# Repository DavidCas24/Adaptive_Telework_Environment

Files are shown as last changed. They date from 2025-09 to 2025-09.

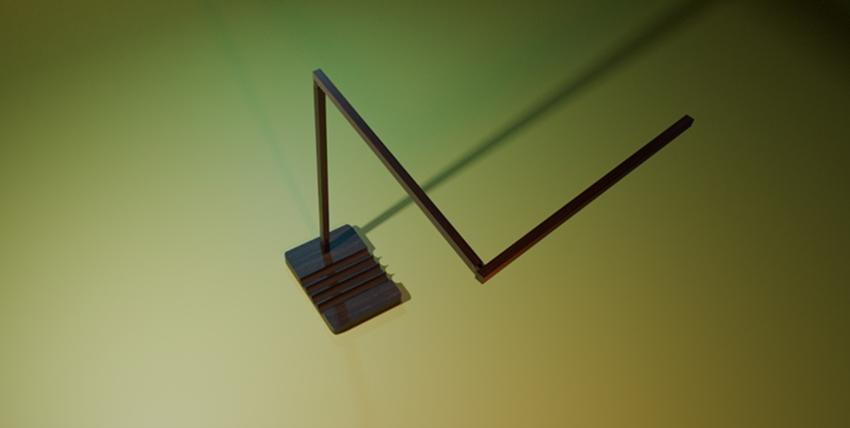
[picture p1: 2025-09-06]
HARDWARE/Render_lamp.png

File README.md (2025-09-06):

# Adaptive Telework Environment with AI-based Smart Lighting

## Overview

This project—developed as part of the IoT Master's Thesis at UNIR—focuses on designing and implementing a cyber-physical smart lamp. It integrates environmental sensors, edge-level AI, IoT connectivity, and dynamic lighting to monitor and classify workspace conditions, ultimately enhancing comfort, productivity, and well-being for remote and hybrid workers.

Render_lamp

## Key Features

- Custom PCB integrating sensors: temperature, humidity, light spectrum, noise, CO₂, VOCs.
- Dynamic lighting control based on open-source WLED.
- TinyML (with Edge Impulse) model on the edge to classify environments as *good, moderate,* or *bad*.
- Real-time visualization via Datacake.
- Interactive online 3D model accessible at: https://lurmis.vercel.app/en

## Repository Structure

Here’s the layout of the project and what each part contains:

```text
HARDWARE/                  → PCB designs, schematics, Gerber files used for fabrication
PCB/                       → Specific PCB layout files (KiCad, Gerber)
Tiny Firmware/             → Minimal firmware examples or template for microcontroller
README.md                  → This documentation file
```
---

##  3D Model

Explore the interactive 3D model of the smart lamp here:
https://lurmis.vercel.app/en

##  Getting Started

1. Clone this repository.
2. Inspect the HARDWARE/ and PCB/ folders for PCB design sources.
3. Use the Tiny Firmware/ folder to explore or flash firmware.
4. Follow the README instructions in each folder to assemble, program, and visualize your setup.

---

##  Dashboard Example / Ejemplo de Dashboard

[Public Datacake Dashboard Example](https://app.datacake.de/dashboard/d/b61564c8-49cd-4808-8c22-bb57cf323bb0)

---

##  System Architecture



---

##  Acknowledgments

SEEEDSTUDIO Fusion PCB Service for sponsoring the manufacturing and assembly of our PCBs and UNIR – Universidad Internacional de La Rioja for the academic guidance.

---

##  License

This project is released under the [MIT License].

---

✍️ Developed by
**David Felipe Castiblanco Cantor** & **Óscar Martínez Cueto**  
Master in IoT – UNIR, 2025

------------------------------------------------------------------------

# Entorno de teletrabajo adaptativo con iluminación inteligente basada en IA

## Resumen

Este proyecto, desarrollado como parte del Trabajo Fin de Máster en IoT en la UNIR, se centra en el diseño e implementación de una lámpara inteligente ciberfísica. Integra sensores ambientales, IA de vanguardia, conectividad IoT e iluminación dinámica para monitorizar y clasificar las condiciones del espacio de trabajo, mejorando así la comodidad, la productividad y el bienestar de los trabajadores remotos e híbridos.

Render_lamp

## Características principales

- PCB personalizada que integra sensores: temperatura, humedad, espectro luminoso, ruido, CO₂, COV.
- Control dinámico de la iluminación basado en WLED de código abierto. - Modelo TinyML (con Edge Impulse) en el borde para clasificar entornos como *buenos, moderados* o *malos*.
- Visualización en tiempo real mediante Datacake.
- Modelo 3D interactivo en línea disponible en: https://lurmis.vercel.app/en

## Estructura del repositorio

A continuación, se muestra el diseño del proyecto y el contenido de cada parte:

```texto
HARDWARE/ → Diseños de PCB, esquemas y archivos Gerber utilizados para la fabricación
PCB/ → Archivos específicos de diseño de PCB (KiCad, Gerber)
Tiny Firmware/ → Ejemplos mínimos de firmware o plantilla para microcontrolador
README.md → Este archivo de documentación
```
---

## Modelo 3D

Explora el modelo 3D interactivo de la lámpara inteligente aquí:
https://lurmis.vercel.app/en

## Primeros pasos

1. Clona este repositorio.
2. Revise las carpetas HARDWARE/ y PCB/ para encontrar las fuentes de diseño de PCB.

3. Use la carpeta Tiny Firmware/ para explorar o actualizar el firmware.

4. Siga las instrucciones del archivo README en cada carpeta para ensamblar, programar y visualizar su configuración.

---

## Ejemplo de Dashboard / Ejemplo de Dashboard

[Ejemplo de Dashboard Público de Datacake](https://app.datacake.de/dashboard/d/b61564c8-49cd-4808-8c22-bb57cf323bb0)

---

## Arquitectura del Sistema



---

## Agradecimientos

A SEEEDSTUDIO Fusion PCB Service por el patrocinio de la fabricación y el ensamblaje de nuestras PCB y a UNIR – Universidad Internacional de La Rioja por la orientación académica.

---

## Licencia

Este proyecto se publica bajo la [Licencia MIT].

---

✍️ Desarrollado por:  
**David Felipe Castiblanco Cantor** & **Óscar Martínez Cueto**  
Master in IoT – UNIR, 2025

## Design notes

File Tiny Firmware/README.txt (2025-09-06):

Run Particle library

The Particle Library deployment option packages all your signal processing blocks, configuration and learning blocks up into a single library (.zip file). You can include this library in your own application to run the impulse locally.

Particle Libraries

To run your Impulse on your Particle board follow these steps:

1. Open a new VS Code window, ensure that Particle Workbench has been installed.
2. Use VS Code Command Palette and type in Particle: Import Project
	a. Select the project.properties file in the directory that you just downloaded and extracted from the section above.
3. Use VS Code Command Palette and type in Particle: Configure Project for Device
	a. Select deviceOS@5.3.2 (or a later version)
	b. Choose a target. (e.g. P2 , this option is also used for the Photon 2).
4. It is sometimes needed to manually put your Device into DFU Mode. You may proceed to the next step, but if you get an error indicating that “No DFU capable USB device available” then please follow these step.
	a. Hold down both the RESET and MODE buttons.
	b. Release only the RESET button, while holding the MODE button.
	c. Wait for the LED to start flashing yellow.
	b. Release the MODE button.
5. Compile and Flash in one command with: Particle: Flash application & DeviceOS (local).

More information: https://docs.edgeimpulse.com/tutorials/topics/inference/run-particle

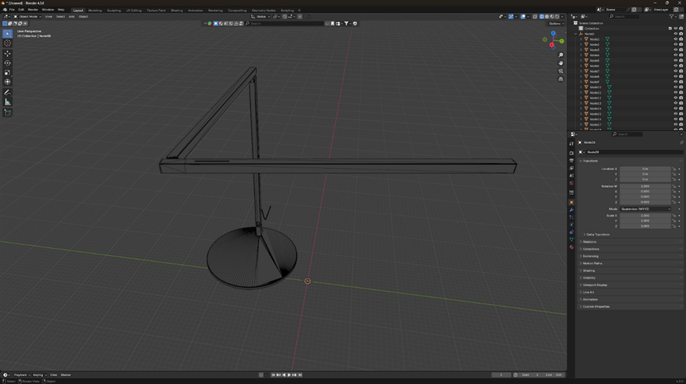
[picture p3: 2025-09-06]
HARDWARE/Blender_desing_lamp.png

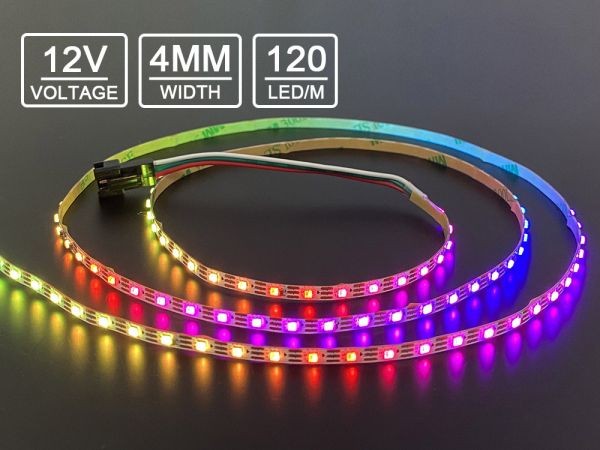
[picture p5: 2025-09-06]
HARDWARE/WS2812B_12V_RBG.jpg

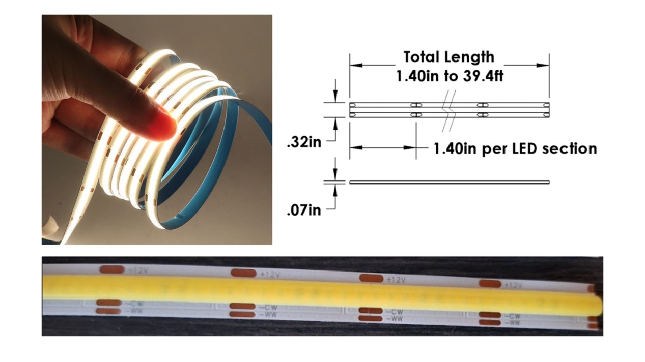
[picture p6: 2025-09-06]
HARDWARE/12V_COB_LED.jpg

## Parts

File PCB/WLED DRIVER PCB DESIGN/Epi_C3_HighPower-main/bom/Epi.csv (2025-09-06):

null | Sourced | Placed | References | Value | Footprint | Quantity
1 |  |  | C1, C8, C11, C13 | 1µF | C_0402_1005Metric | 4
2 |  |  | C16, C17 | 22µF | C_0805_2012Metric | 2
3 |  |  | C10 | 10µF | C_0805_2012Metric | 1
4 |  |  | C15 | 100nF | C_0402_1005Metric | 1
5 |  |  | R6, R7, R9, R10, R11, R12, R13, R14 | 10K | R_0402_1005Metric | 8
6 |  |  | R3, R8, R15 | 1K | R_0402_1005Metric | 3
7 |  |  | R1 | TBD | R_0402_1005Metric | 1
8 |  |  | L2 | TBD | L_Abracon_ASPI-0425 | 1
9 |  |  | D1 | D_Small | D_SOD-128 | 1
10 |  |  | U1 | ESP32-C3-MINI-1 | ESP32-C3-MINI-1 | 1
11 |  |  | U2 | MIC5219-3.3YM5 | SOT-23-5 | 1
12 |  |  | U3 | ~ | SOIC-10_3.9x4.9mm_P1mm | 1
13 |  |  | U5 | AP63205WU | TSOT-23-6 | 1
14 |  |  | SW2 | SW_MEC_5G | R-668048 | 1
15 |  |  | JP1, JP2, JP3, JP4 | Jumper | SolderJumper-2_P1.3mm_Open_RoundedPad1.0x1.5mm | 4
16 |  |  | Q1, Q2, Q3, Q4 | Q_NMOS_GSD | SOT-23 | 4
17 |  |  | RV3 | Varistor | R_0402_1005Metric | 1
18 |  |  | J1 | Conn_01x08 | PinHeader_1x08_P2.54mm_Vertical | 1
19 |  |  | J2 | USB_C_Receptacle_USB2.0 | USB_C_Receptacle_G-Switch_GT-USB-7010ASV | 1
20 |  |  | J4 | Conn_01x01 | TestPoint_Pad_3.0x3.0mm | 1
21 |  |  | J5 | Conn_01x09 | PinHeader_1x09_P2.54mm_Vertical | 1
22 |  |  | J7 | Conn_02x03 | PinHeader_2x03_P2.54mm_Horizontal | 1
23 |  |  | J8 | Conn_01x03 | PinHeader_1x03_P2.54mm_Vertical | 1

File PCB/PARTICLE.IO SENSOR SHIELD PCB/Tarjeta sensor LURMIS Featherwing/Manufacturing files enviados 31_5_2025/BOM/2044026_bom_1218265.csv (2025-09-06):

Designator | Manufacturer Part Number or Seeed SKU | Quantity | Link
U2 | AB1805-T3 | 1 | https://item.hqchip.com/1102748861.html
R1 | RC0603JR-071K5L | 1
R2,R3 | RMCF0603JT10K0 | 2 | https://item.hqchip.com/1101293532.html
Q1 | ABS07-120-32.768KHZ-T | 1
C3 | EMCP500G470M1GV001T | 1 | https://item.hqchip.com/1100650671.html
R4,R5 | RG1608P-104-B-T5 | 2 | https://item.hqchip.com/1101325767.html
Q2 | 2N7002L | 1 | https://item.hqchip.com/1103150596.html
U1 | AS7341-DLGT | 1 | https://item.hqchip.com/1105780271.html
R6,R7,R8 | CRGCQ0603J2K2 | 3 | https://item.hqchip.com/1105771346.html
C5 | CC0603KRX7R7BB104 | 1
U3 | AP2127K-1.8TRG1 | 1 | https://item.hqchip.com/1103060261.html
C2,C4 | CL10B105KP8NNNC | 2
R9,R10,R11 | CR0603-JW-102ELF | 3 | https://item.hqchip.com/1101334259.html
D1 | LTST-C190KRKT | 1 | https://item.hqchip.com/1100067616.html
D2 | MP-3014-1100-50-70 | 1 | https://item.hqchip.com/1106299875.html
D3 | APT1608SF4C-PRV | 1 | https://item.hqchip.com/1103075460.html
J1 | SM04B-SRSS-TB(LF)(SN) | 1
D4,D5 | LTST-C190GKT | 2 | https://item.hqchip.com/1100067619.html
JP1 | TSM-102-01-L-SV | 1 | https://item.hqchip.com/1102248009.html
JP3 | TSM-105-01-L-SV | 1 | https://item.hqchip.com/1036858135.html

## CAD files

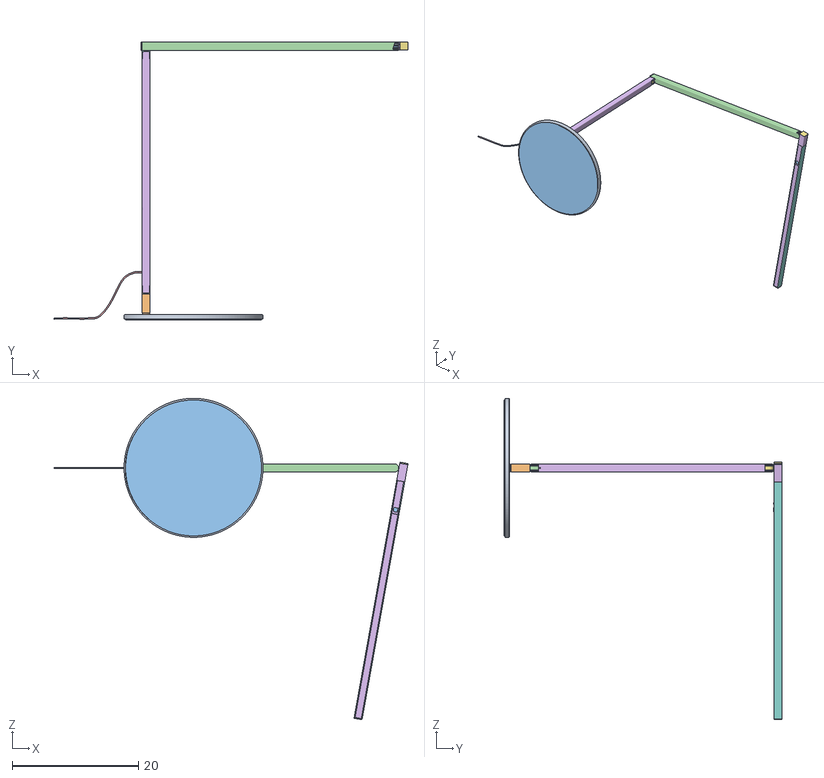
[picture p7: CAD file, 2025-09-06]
HARDWARE/DISEÑO_LAMPARA_3D/Z-Bar Gen 4.obj
56.0 x 44.0 x 50.8

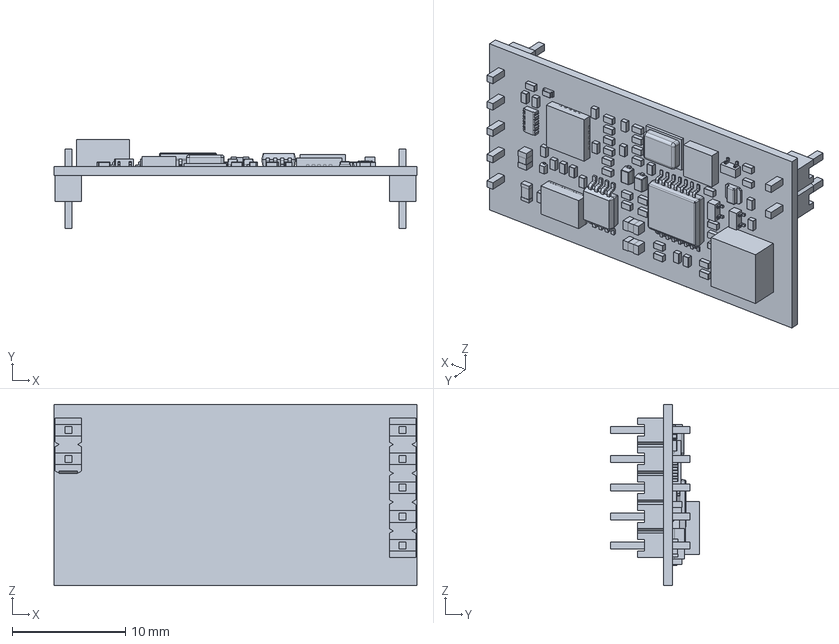
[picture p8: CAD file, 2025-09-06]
PCB/3D/Ambimate.stp
32.0 x 7.84 x 16.0 mm

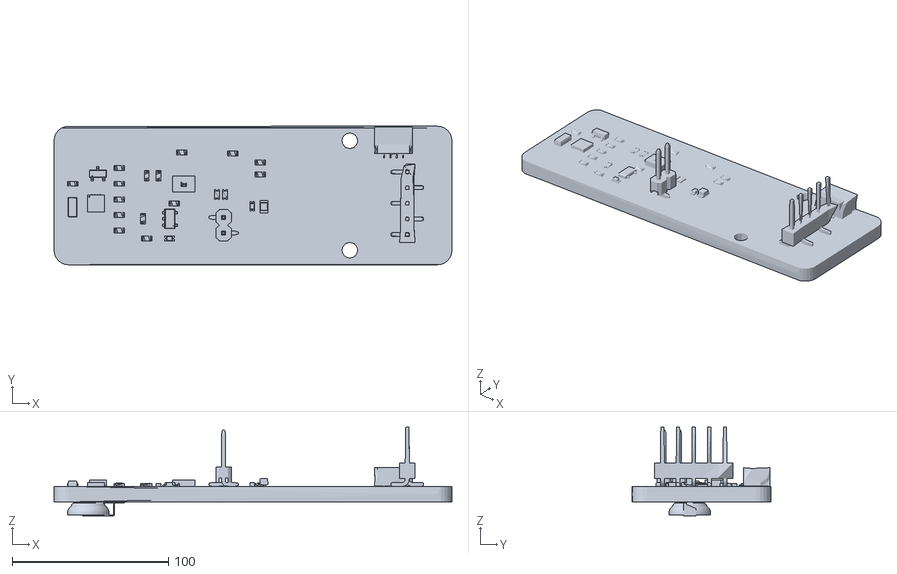
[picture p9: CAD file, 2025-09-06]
PCB/PARTICLE.IO SENSOR SHIELD PCB/MECHANICAL Modelo 3D/OBJ_FeatherAB1805-SC_FINAL_2.obj
254.8 x 88.8 x 56.8

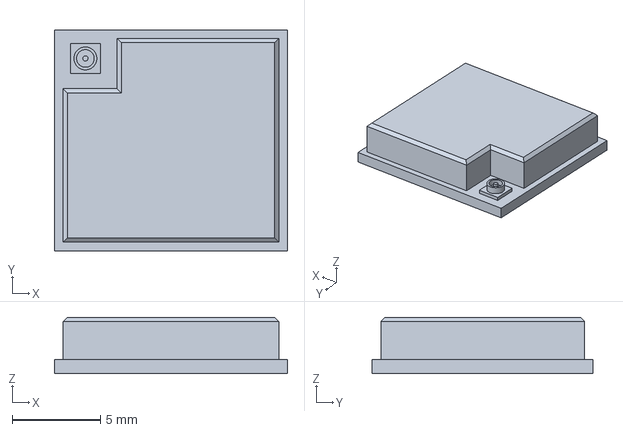
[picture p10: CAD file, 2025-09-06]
PCB/WLED DRIVER PCB DESIGN/Epi_C3_HighPower-main/ESP32-C3-MINI-1U.FCStd
13.2 x 12.5 x 3.20 mm

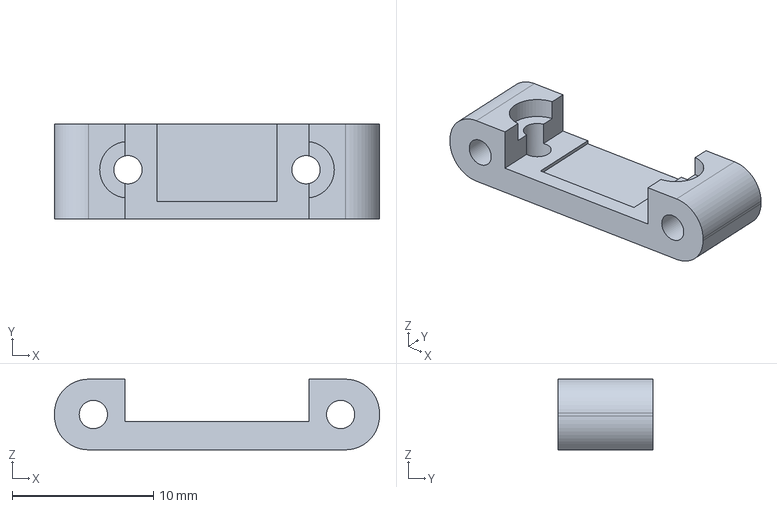
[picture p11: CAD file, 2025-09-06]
PCB/WLED DRIVER PCB DESIGN/Epi_C3_HighPower-main/extra/panelmount.FCStd
23.0 x 6.75 x 5.00 mm

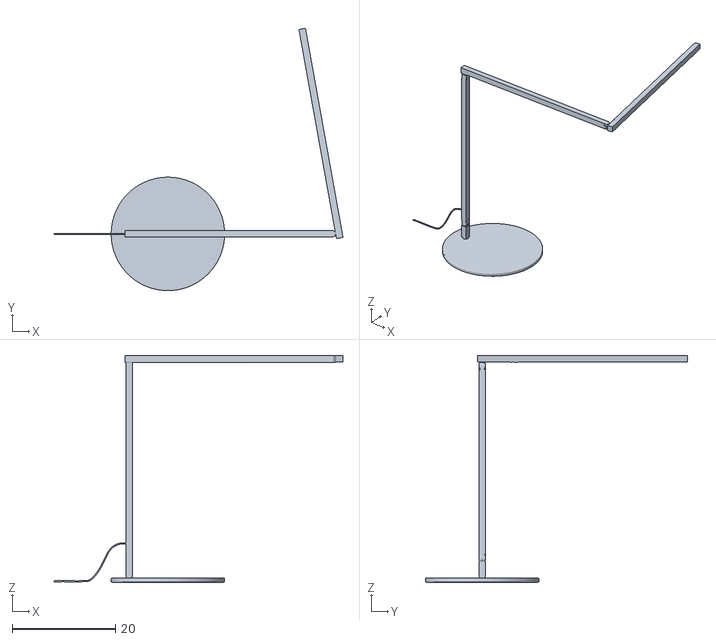
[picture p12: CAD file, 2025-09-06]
HARDWARE/DISEÑO_LAMPARA_3D/lampara.stl
56.0 x 50.8 x 44.0

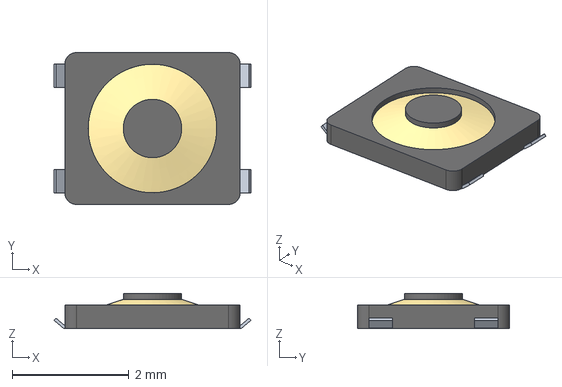
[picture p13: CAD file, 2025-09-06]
PCB/WLED DRIVER PCB DESIGN/Epi_C3_HighPower-main/extra/knapp (2023_01_16 13_30_41 UTC).stp
3.37 x 2.60 x 0.6 mm

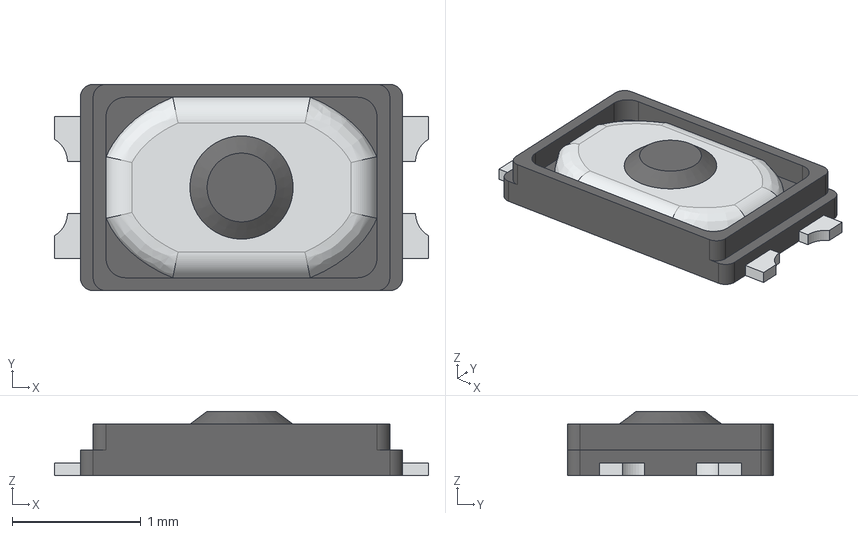
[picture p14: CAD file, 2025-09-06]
PCB/WLED DRIVER PCB DESIGN/Epi_C3_HighPower-main/extra/R-668048_sw.stp
2.90 x 1.60 x 0.5 mm

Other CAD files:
PCB/PARTICLE.IO SENSOR SHIELD PCB/MECHANICAL Modelo 3D/argon-v1.f3d
PCB/WLED DRIVER PCB DESIGN/Epi_C3_HighPower-main/extra/panelmount.obj

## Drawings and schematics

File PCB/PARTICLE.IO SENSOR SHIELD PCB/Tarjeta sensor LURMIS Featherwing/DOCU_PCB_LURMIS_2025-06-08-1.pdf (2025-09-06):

A | A

1

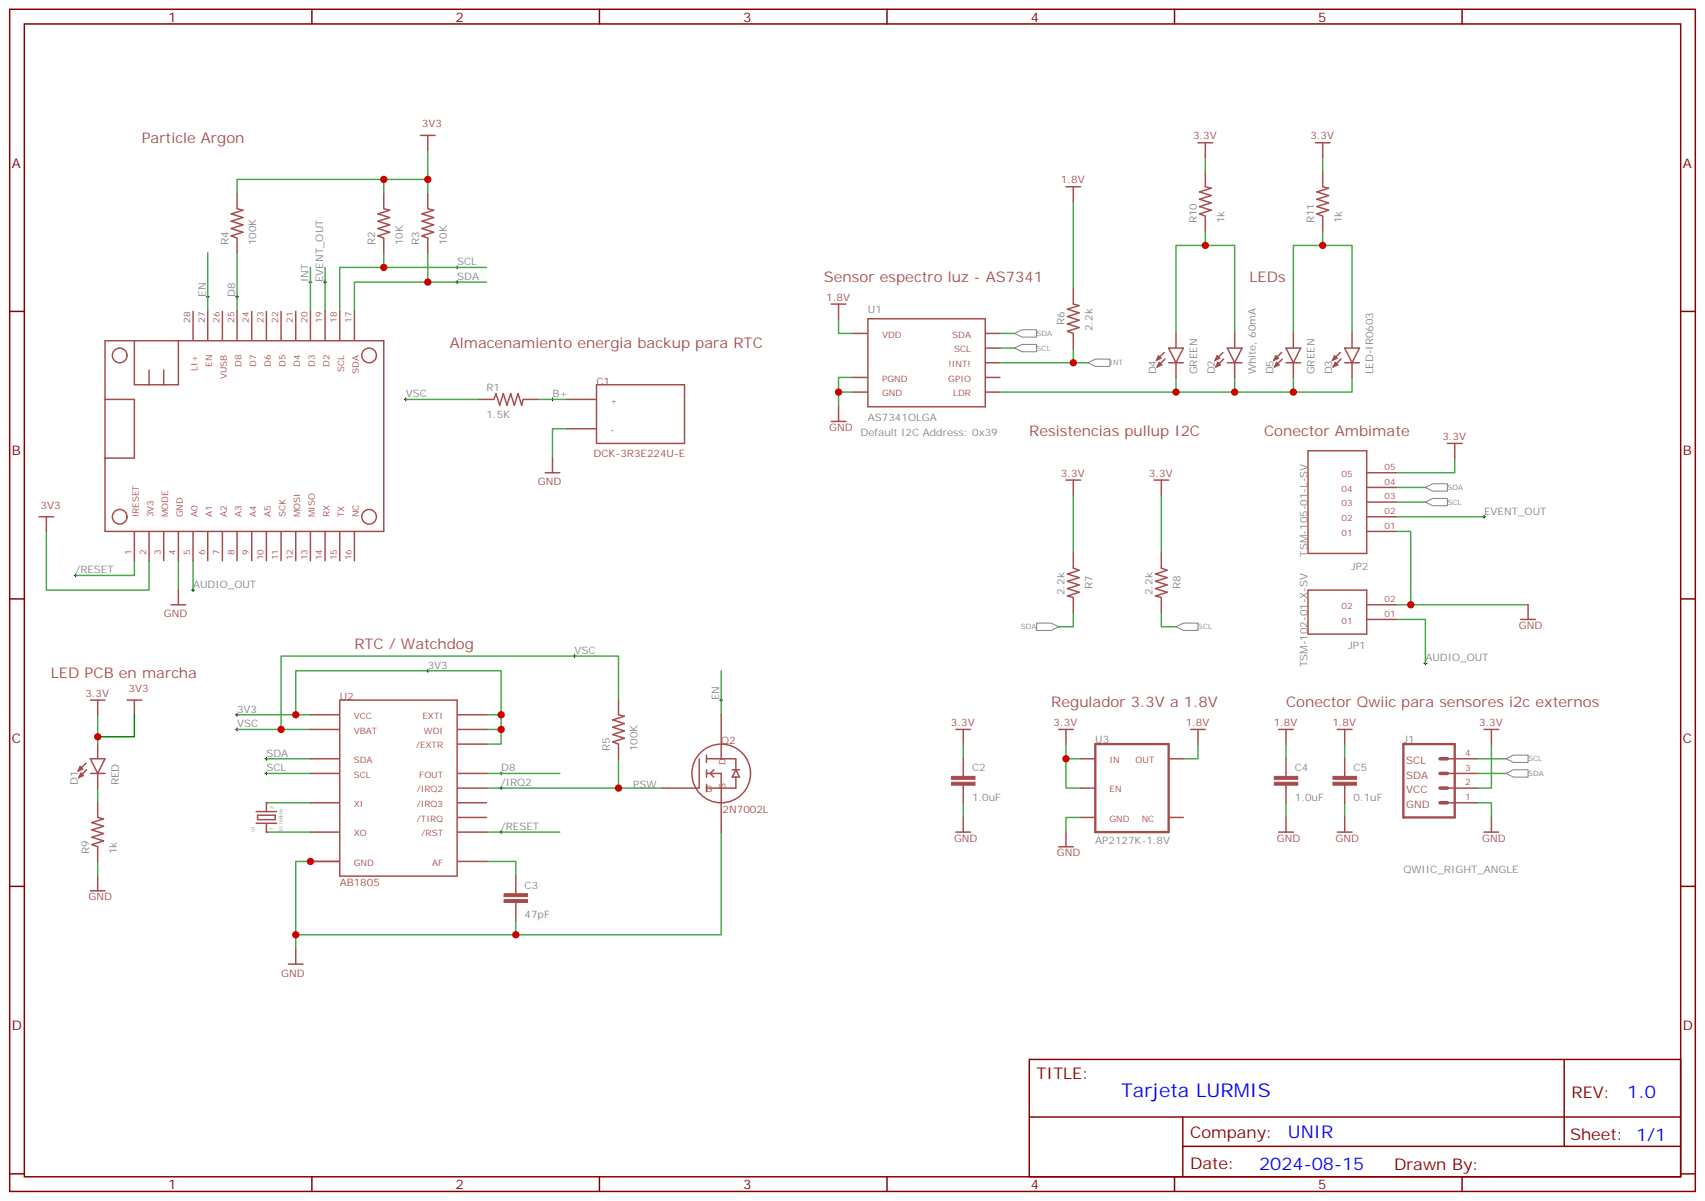
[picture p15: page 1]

Almacenamiento energia backup para RTC

LED PCB en marcha

Conector Qwiic para sensores i2c externos

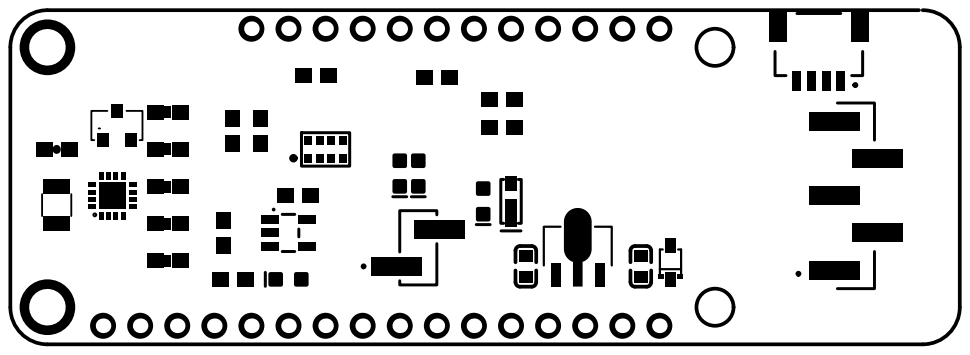
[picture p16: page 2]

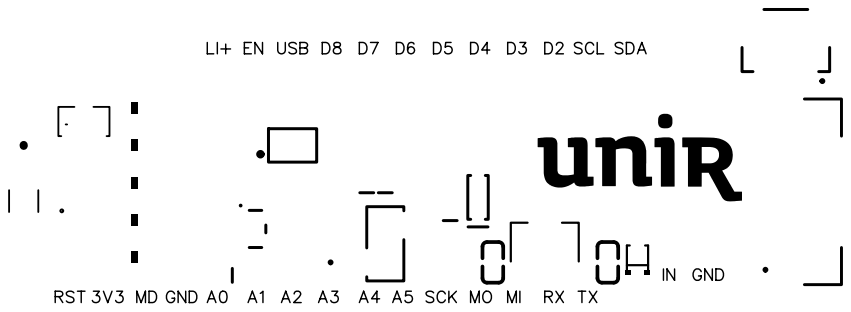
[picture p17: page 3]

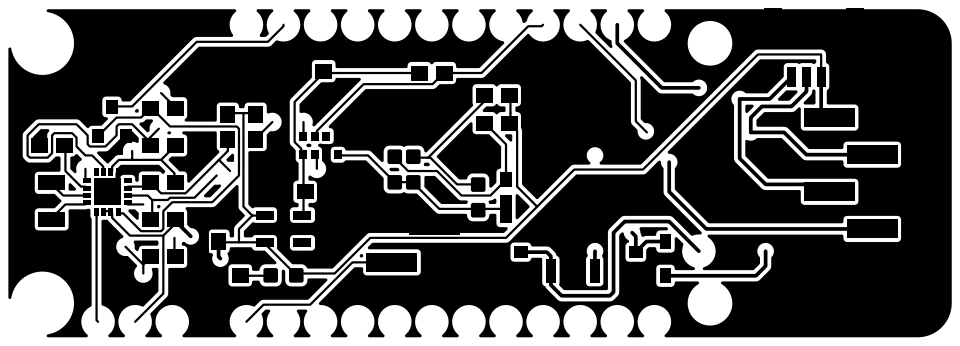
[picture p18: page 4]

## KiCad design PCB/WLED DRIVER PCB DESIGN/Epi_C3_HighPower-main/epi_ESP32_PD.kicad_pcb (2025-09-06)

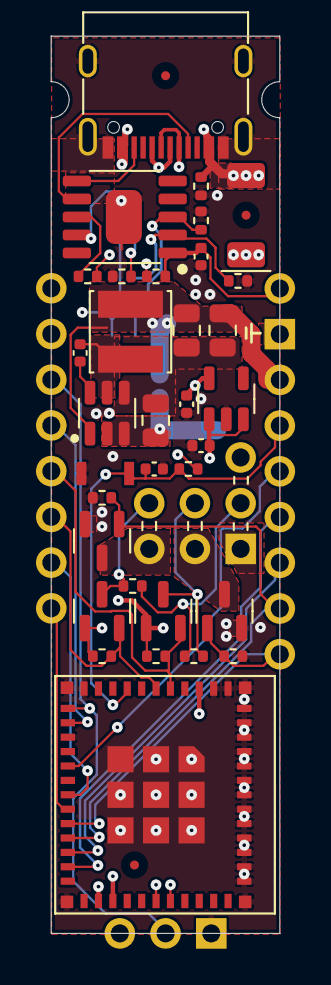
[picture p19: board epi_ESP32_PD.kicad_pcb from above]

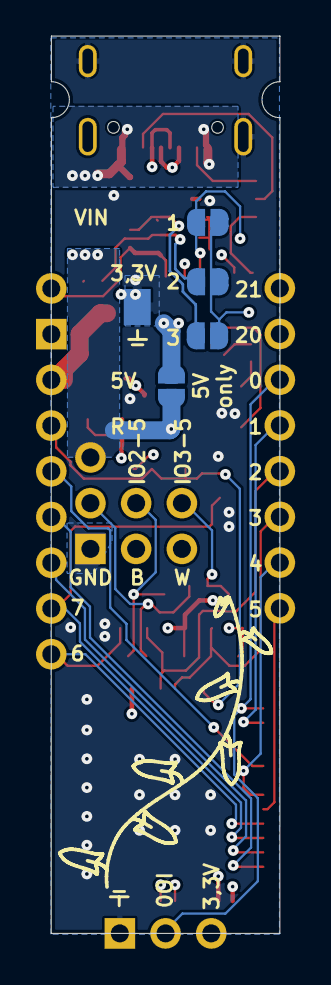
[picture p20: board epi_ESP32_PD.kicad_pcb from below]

Board: 4 copper layers, 12.7 x 49.8 mm, 42 parts (5 on the bottom side), 33 nets.

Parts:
C1, C8, C11, C13: 1µF; C_0402_1005Metric
C10: 10µF; C_0805_2012Metric
C15: 100nF; C_0402_1005Metric
C16, C17: 22µF; C_0805_2012Metric
D1: D_Small; D_SOD-128
J1: Conn_01x08; PinHeader_1x08_P2.54mm_Vertical
J2: USB_C_Receptacle_USB2.0; USB_C_Receptacle_G-Switch_GT-USB-7010ASV
J4: Conn_01x01; TestPoint_Pad_3.0x3.0mm
J5: Conn_01x09; PinHeader_1x09_P2.54mm_Vertical
J7: Conn_02x03; PinHeader_2x03_P2.54mm_Horizontal
J8: Conn_01x03; PinHeader_1x03_P2.54mm_Vertical
JP1, JP2, JP3, JP4: Jumper; SolderJumper-2_P1.3mm_Open_RoundedPad1.0x1.5mm
L2: TBD; L_Abracon_ASPI-0425
Q1, Q2, Q3, Q4: Q_NMOS_GSD; SOT-23
R1: TBD; R_0402_1005Metric
R3, R8, R15: 1K; R_0402_1005Metric
R6: 10kΩ; R_0402_1005Metric
R7, R9, R10, R11, R12, R13, R14: 10K; R_0402_1005Metric
RV3: Varistor; R_0402_1005Metric
SW2: SW_MEC_5G; R-668048
U1: ESP32-C3-MINI-1
U2: MIC5219-3.3YM5; SOT-23-5
U3: SOIC-10_3.9x4.9mm_P1mm
U5: AP63205WU; TSOT-23-6

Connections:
+3.3V: C1.2, C8.1, J5.1, J8.1, JP1.1 (A), JP2.1 (A), JP3.2 (B), Q1.1 (G), Q2.1 (G), R1.1, R6.1, R9.2, R11.2, U1.3 (3V3), U2.5 (OUT), U3.1 (VDD)
+5V: C13.2, C16.2, C17.2, J5.3, J7.1, JP4.1 (A), L2.2, R10.2, R12.2, U2.1 (IN), U2.3 (EN), U5.1 (FB)
/buck: C15.2, L2.1, U5.5 (SW)
B: J7.4, Q4.3 (D)
BOOT: J5.6, U1.23 (GPIO9)
D+: J2.A6 (D+), J2.B6 (D+), U1.27 (GPIO19/USB_D+)
D-: J2.A7 (D-), J2.B7 (D-), U1.26 (GPIO18/USB_D-)
EN: C11.2, J5.4, R6.2, SW2.1 (A), U1.8 (EN/CHIP_PU)
GND: C1.1, C8.2, C10.1, C11.1, C13.1, C16.1, C17.1, J2.A1 (GND), J2.A12 (GND), J2.B1 (GND), J2.B12 (GND), J2.S1 (SHIELD), J4.1, J5.2, J7.2, J8.3, Q3.2 (S), Q4.2 (S), R3.1, R8.1, R13.1, R14.1, R15.1, RV3.2, SW2.3 (B), U1.1 (GND), U1.2 (GND), U1.11 (GND), U1.14 (GND), U1.36 (GND), U1.37 (GND), U1.38 (GND), U1.39 (GND), U1.40 (GND), U1.41 (GND), U1.42 (GND), U1.43 (GND), U1.44 (GND), U1.45 (GND), U1.46 (GND), U1.47 (GND), U1.48 (GND), U1.49 (GND), U1.50 (GND), U1.51 (GND), U1.52 (GND), U1.53 (GND), U2.2 (GND), U3.0 (GND), U5.4 (GND)
IO0: J1.3, J8.2, U1.12 (GPIO0/ADC1_CH0/XTAL_32K_P)
IO1: J1.4, U1.13 (GPIO1/ADC1_CH1/XTAL_32K_N)
IO2: J1.5, Q1.2 (S), R9.1, U1.5 (GPIO2/ADC1_CH2)
IO2_5V: J7.3, Q1.3 (D), R10.1
IO3: J1.6, Q2.2 (S), R11.1, U1.6 (GPIO3/ADC1_CH3)
IO3_5V: J7.5, Q2.3 (D), R12.1
IO4: J1.7, U1.18 (GPIO4/ADC1_CH4)
IO5: J1.8, U1.19 (GPIO5/ADC2_CH0)
IO6: J5.9, Q4.1 (G), R13.2, U1.20 (GPIO6)
IO7: J5.8, Q3.1 (G), R14.2, U1.21 (GPIO7)
IO8: J5.7, U1.22 (GPIO8)
IO10: J5.5, U1.16 (GPIO10)
unnamed: J2.A5 (CC1), U3.7 (CC1)
unnamed: J2.B5 (CC2), U3.6 (CC2)
unnamed: JP1.2 (B), R8.2, U3.2 (CFG2)
unnamed: JP2.2 (B), R3.2, U3.3 (CFG3)
unnamed: JP3.1 (A), R15.2, U3.9 (CFG1)
unnamed: R7.2, U3.8 (VBUS)
unnamed: C15.1, U5.6 (BST)
PD: D1.2 (A), J2.A4 (VBUS), J2.A9 (VBUS), J2.B4 (VBUS), J2.B9 (VBUS), R1.2, R7.1, RV3.1
U0RXD: J1.2, U1.30 (GPIO20/U0RXD)
U0TXD: J1.1, U1.31 (GPIO21/U0TXD)
VIN: C10.2, D1.1 (K), J7.0, JP4.2 (B), U5.2 (EN), U5.3 (IN)
W: J7.6, Q3.3 (D)

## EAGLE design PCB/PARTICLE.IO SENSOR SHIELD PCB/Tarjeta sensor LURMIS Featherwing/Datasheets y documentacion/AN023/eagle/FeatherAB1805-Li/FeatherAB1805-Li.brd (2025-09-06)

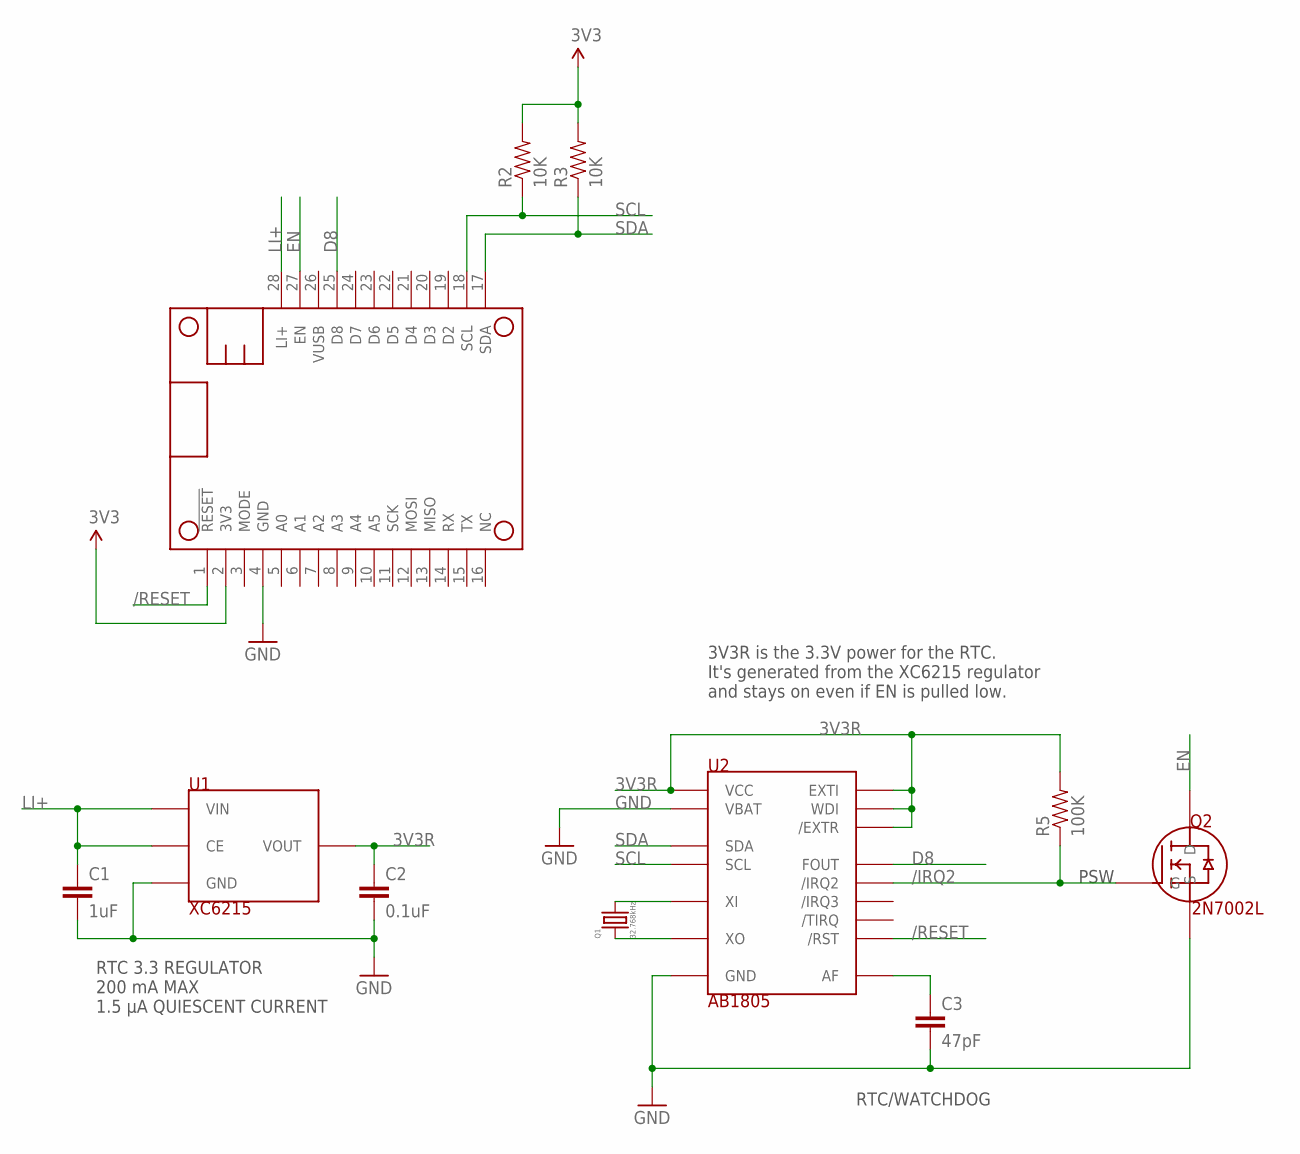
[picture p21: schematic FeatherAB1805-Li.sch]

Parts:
C1: 1uF; 0603-CAP
C2: 0.1uF; 0603-CAP
C3: 47pF; 0603-CAP
MS1: FEATHERWING_NODIM
Q1: 32.768kHz; ABS07-120-CRYSTAL
Q2: 2N7002L
R2, R3: 10K; 0603-RES
R5: 100K; 0603-RES
U1: XC6215; SOT-25-TOREX
U2: AB1805; 16-VFQFN-ABRACON

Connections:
3V3: MS1.2 (3V3), R2.2, R3.2
3V3R: C2.1, R5.2, U1.5 (VOUT), U2.2 (WDI), U2.3 (/EXTR), U2.10 (EXTI), U2.13 (VCC)
/IRQ2: Q2.1 (G), R5.1, U2.4 (/IRQ2)
/RESET: MS1.1 (!RESET), U2.1 (/RST)
AF: C3.1, U2.14 (AF)
D8: MS1.25 (D8), U2.11 (FOUT)
EN: MS1.27 (EN), Q2.3 (D)
GND: C1.2, C2.2, C3.2, MS1.4 (GND), Q2.2 (S), U1.2 (GND), U2.5 (VBAT), U2.9 (GND), U2.EP (GND)
LI+: C1.1, MS1.28 (LI+), U1.1 (VIN), U1.3 (CE)
SCL: MS1.18 (SCL), R2.1, U2.7 (SCL)
SDA: MS1.17 (SDA), R3.1, U2.6 (SDA)
XI: Q1.2, U2.16 (XI)
XO: Q1.1, U2.15 (XO)

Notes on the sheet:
RTC 3.3 REGULATOR 200 mA MAX 1.5 µA QUIESCENT CURRENT
PSW
RTC/WATCHDOG
3V3R is the 3.3V power for the RTC. It's generated from the XC6215 regulator and stays on even if EN is pulled low.

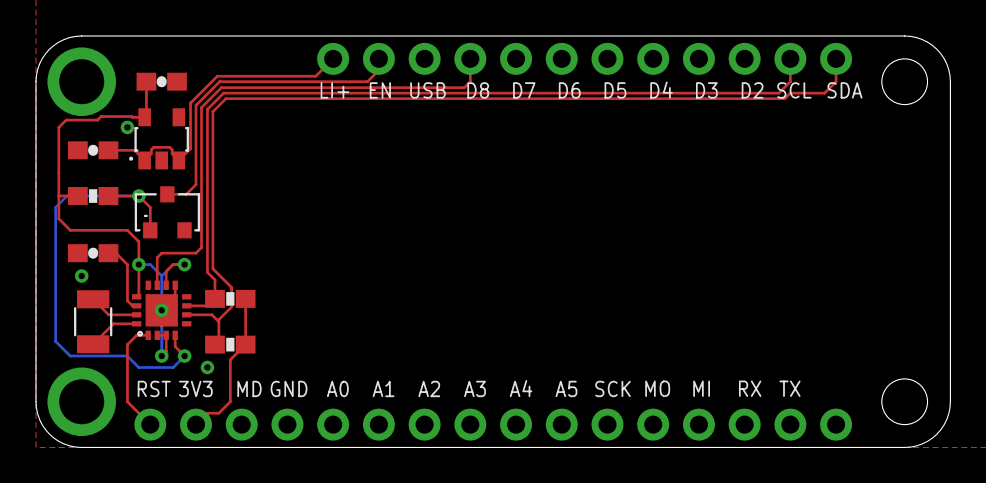
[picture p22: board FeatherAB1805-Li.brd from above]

Board: 2 copper layers, 50.8 x 22.9 mm, 11 parts (0 on the bottom side), 13 nets.

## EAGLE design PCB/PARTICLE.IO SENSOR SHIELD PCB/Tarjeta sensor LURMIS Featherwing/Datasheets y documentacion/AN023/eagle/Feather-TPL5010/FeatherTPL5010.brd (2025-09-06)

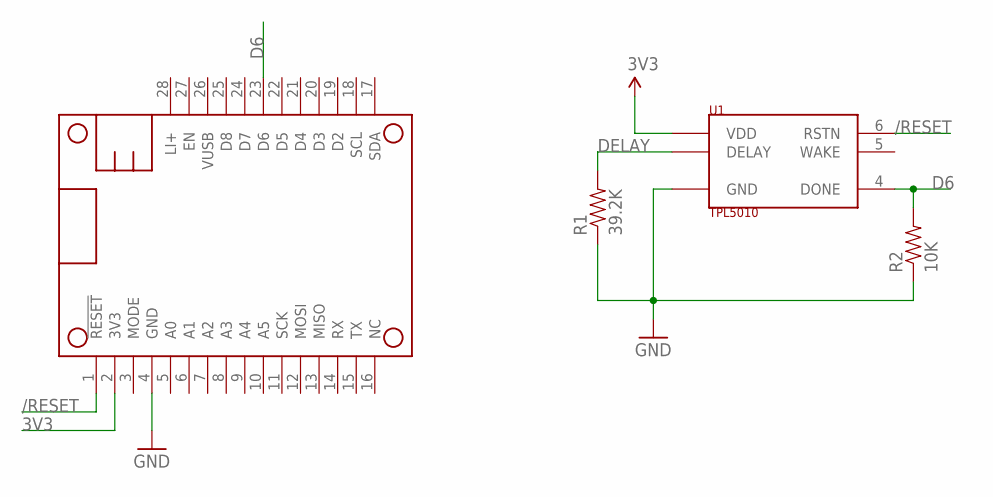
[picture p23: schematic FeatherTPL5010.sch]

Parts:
MS1: FEATHERWING_NODIM
R1: 39.2K; 0603-RES
R2: 10K; 0603-RES
U1: TPL5010; SOT-23-6-TI

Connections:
3V3: MS1.2 (3V3), U1.1 (VDD)
/RESET: MS1.1 (!RESET), U1.6 (RSTN)
D6: MS1.23 (D6), R2.2, U1.4 (DONE)
DELAY: R1.2, U1.3 (DELAY)
GND: MS1.4 (GND), R1.1, R2.1, U1.2 (GND)

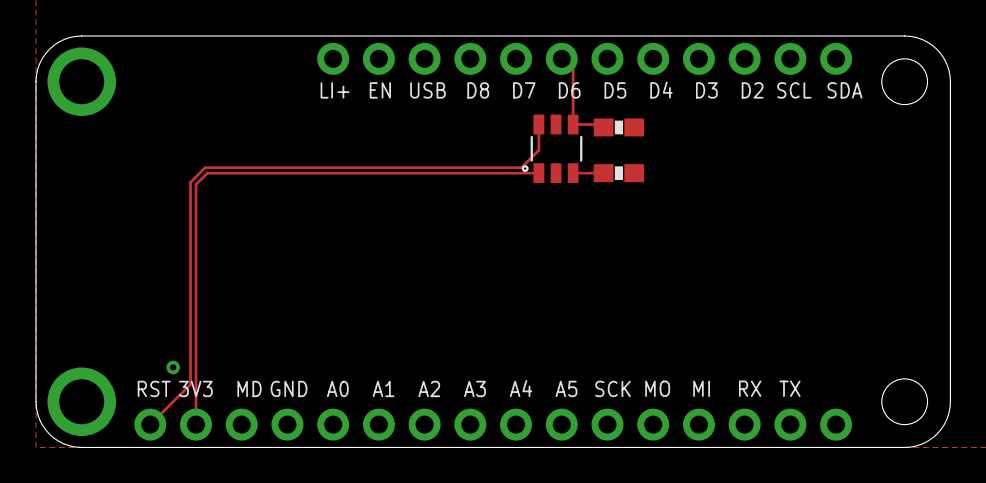
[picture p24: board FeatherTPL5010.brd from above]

Board: 2 copper layers, 50.8 x 22.9 mm, 4 parts (0 on the bottom side), 5 nets.

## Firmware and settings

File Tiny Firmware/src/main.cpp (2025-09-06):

#include <Particle.h>               // Librería principal de Particle (manejo del hardware y conectividad)
#include <Wire.h>                   // Para comunicación I2C (sensores)
#include <Adafruit_AS7341.h>       // Librería para controlar el sensor espectral AS7341
#include <UNIR_inferencing.h>      // Librería generada por Edge Impulse para ejecutar inferencias

SYSTEM_THREAD(ENABLED);            // Permite que el sistema ejecute procesos de red en paralelo al loop
SerialLogHandler logHandler(LOG_LEVEL_ERROR); // Solo muestra errores en el log serial

Adafruit_AS7341 as7341;            // Instancia del sensor AS7341

unsigned char buf[20];             // Buffer para guardar los datos del sensor AmbiMate
unsigned long lastSampleTime = 0;  // Control de tiempo de última muestra
float sampPeriod = 30000;          // Periodo de muestreo: cada 30 segundos

#define NORMALIZE(val, min, range) ((val - min) / range)  // Macro para normalizar un valor

const float mins[6]   = {20.00, 30.14, 103.00, 0.00, 403.00, 0.00};     // Valores mínimos de calibración
const float ranges[6] = {13.95, 49.30, 691.00, 9.00, 1595.00, 299.00};  // Rangos de cada variable

static float features[16];         // Arreglo con 16 entradas: 6 ambientales + 10 espectrales

int raw_feature_get_data(size_t offset, size_t length, float *out_ptr) { // Función que usa el clasificador para obtener los datos del array features
    memcpy(out_ptr, features + offset, length * sizeof(float));          // Copia los datos de features al puntero de salida
    return 0;                                                             // Retorna 0 indicando éxito
}

void setup() {
    Serial.begin(115200);                                 // Inicia comunicación Serial
    waitFor(Serial.isConnected, 15000);                   // Espera a que el puerto esté conectado
    delay(2000);                                          // Espera adicional de 2 segundos

    if (!as7341.begin()) {                                // Inicializa el AS7341
        Particle.publish("Error", "AS7341 no encontrado"); // Publica un error si no se detecta
        while (1) delay(10);                              // Detiene ejecución
    }

    as7341.setATIME(100);                                 // Configura tiempo de integración
    as7341.setASTEP(999);                                 // Configura pasos de integración
    as7341.setGain(AS7341_GAIN_256X);                     // Configura ganancia

    Wire.begin();                                         // Inicia I2C
    Particle.publish("Inicio", "Dispositivo inicializado"); // Mensaje de inicialización
}

void recolectarDatos() {
    Wire.beginTransmission(0x2A);                         // Dirección del sensor AmbiMate
    Wire.write(byte(0xC0)); Wire.write(byte(0x7F));       // Comando de disparo
    Wire.endTransmission();                               // Finaliza transmisión
    delay(100);                                           // Espera para adquisición
    Wire.beginTransmission(0x2A);                         // Nueva transmisión para lectura
    Wire.write(byte(0x00));                               // Dirección para leer datos
    Wire.endTransmission();                               // Finaliza transmisión
    Wire.requestFrom(0x2A, 15);                           // Solicita 15 bytes de datos
    for (int i = 0; i < 15; i++) buf[i] = Wire.read();    // Lee y guarda en buf

    float tempC = (buf[1] * 256.0 + buf[2]) / 10.0;        // Temperatura (°C)
    float hum = (buf[3] * 256.0 + buf[4]) / 10.0;          // Humedad relativa (%)
    float light = (buf[5] * 256.0 + buf[6]);               // Luz ambiental (lux)
    float audio = (buf[7] * 256.0 + buf[8]);               // Nivel de sonido (unidad relativa)
    float co2 = (buf[11] * 256.0 + buf[12]);               // CO2 (ppm)
    float voc = (buf[13] * 256.0 + buf[14]);               // Compuestos orgánicos volátiles (ppb)

    features[0] = NORMALIZE(tempC, mins[0], ranges[0]);    // Normaliza y asigna temperatura
    features[1] = NORMALIZE(hum,    mins[1], ranges[1]);   // Normaliza y asigna humedad
    features[2] = NORMALIZE(light,  mins[2], ranges[2]);   // Normaliza y asigna luz
    features[3] = NORMALIZE(audio,  mins[3], ranges[3]);   // Normaliza y asigna sonido
    features[4] = NORMALIZE(co2,    mins[4], ranges[4]);   // Normaliza y asigna CO2
    features[5] = NORMALIZE(voc,    mins[5], ranges[5]);   // Normaliza y asigna VOC

    uint16_t readings[12];                                // Lecturas RAW del espectro
    float counts[12];                                     // Lecturas convertidas a basic counts
    if (as7341.readAllChannels(readings)) {               // Si la lectura fue exitosa
        for (int i = 0; i < 12; i++) {
            counts[i] = as7341.toBasicCounts(readings[i]); // Conversión de lectura a unidad básica
        }

        features[6]  = counts[0];   // 415nm (violeta)
        features[7]  = counts[1];   // 445nm (azul)
        features[8]  = counts[2];   // 480nm (cyan)
        features[9]  = counts[3];   // 515nm (verde)
        features[10] = counts[6];   // 555nm (amarillo)
        features[11] = counts[7];   // 590nm (naranja)
        features[12] = counts[8];   // 630nm (rojo-naranja)
        features[13] = counts[9];   // 680nm (rojo)
        features[14] = counts[10];  // Intensidad total del espectro
        features[15] = counts[11];  // Infrarrojo cercano (NIR)
    } else {
        Particle.publish("Error", "Lectura AS7341 fallida"); // Publica error si la lectura falla
    }
}

void ejecutarInferencia() {
    ei_impulse_result_t result = { 0 };                   // Estructura donde se guarda el resultado
    signal_t features_signal;                             // Señal que representa los datos de entrada
    features_signal.total_length = sizeof(features) / sizeof(features[0]); // Largo del vector
    features_signal.get_data = &raw_feature_get_data;     // Función que proporciona los datos al modelo

    EI_IMPULSE_ERROR res = run_classifier(&features_signal, &result, false); // Ejecuta inferencia
    if (res != EI_IMPULSE_OK) {                           // Si hay error en la inferencia
        ei_printf("Error de inferencia: (%d)\n", res);    // Muestra el error por consola
        return;                                           // Sale de la función
    }

    String msg = "Inferencia: ";                          // Mensaje base
    for (uint16_t i = 0; i < EI_CLASSIFIER_LABEL_COUNT; i++) { // Recorre cada categoría
        msg += String(ei_classifier_inferencing_categories[i]) + ": "; // Agrega nombre de categoría
        msg += String(result.classification[i].value, 5);  // Agrega valor de probabilidad
        if (i < EI_CLASSIFIER_LABEL_COUNT - 1) msg += ", "; // Agrega coma si no es la última
    }

    #if EI_CLASSIFIER_HAS_ANOMALY == 1
        msg += ", Anomalía: ";                            // Si el modelo detecta anomalías
        msg += String(result.anomaly, 3);                 // Agrega valor de anomalía
    #endif

    Particle.publish("Inferencia_Resultados", msg, PRIVATE); // Publica resultados en la nube (modo privado)
}

void loop() {
    if (millis() - lastSampleTime >= sampPeriod) {        // Verifica si ha pasado el tiempo de muestreo
        lastSampleTime = millis();                        // Actualiza la marca de tiempo
        recolectarDatos();                                // Llama a función de recolección
        ejecutarInferencia();                             // Ejecuta la inferencia con los datos
    }
}

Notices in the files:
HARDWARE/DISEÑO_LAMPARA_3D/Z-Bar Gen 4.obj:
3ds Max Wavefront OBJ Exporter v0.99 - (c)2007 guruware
